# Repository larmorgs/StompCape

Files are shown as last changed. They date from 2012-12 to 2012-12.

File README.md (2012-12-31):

Stomp Cape
=======

Greg Larmore and Matt Moravec

This is the repository for the Stomp Cape--a BeagleBone cape for an open source guitar effects stomp pedal. The pedal will leverage the power of 32-bit embedded linux on the BeagleBone and will be reconfigurable using node.js.

Current Status
=======

Currently the schematic for the cape has been created and is being validated. Software to support the cape is under development.

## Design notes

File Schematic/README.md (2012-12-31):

Stomp Cape
=======

Greg Larmore and Matt Moravec

This is the schematic for the Stomp Cape created in Eagle 6.3.0. It uses the built in Eagle libraries along with the libraries located in the ./lbr folder.

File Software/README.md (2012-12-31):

Stomp Cape
=======

Greg Larmore and Matt Moravec

This is the software that accompanies the cape.

CURRENTLY UNDER DEVELOPMENT.

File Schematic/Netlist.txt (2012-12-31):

Netlist

Exported from BeagleBone-Stomp-v0.1.sch at 12/31/2012 1:25:14 PM

EAGLE Version 6.3.0 Copyright (c) 1988-2012 CadSoft

Net      Part     Pad      Pin        Sheet

1.8V     C18      1        P$1        1
         C4       2        P$2        1
         C5       1        P$1        1
         R1       1        1          1
         U2       3        DVDD       1
         U3       1        OUT        1

3.3V     C1       1        P$1        1
         C11      1        P$1        1
         C14      1        P$1        1
         C19      1        P$1        1
         C2       1        P$1        1
         C6       1        P$1        1
         C7       1        P$1        1
         C8       1        P$1        1
         C9       1        P$1        1
         J1       4        VCC_IN     1
         JP3      1        1          1
         JP3      2        2          1
         JP3      3        3          1
         JP3      4        4          1
         JP3      5        5          1
         JP3      6        6          1
         R10      1        1          1
         R11      1        1          1
         R12      1        1          1
         R13      1        1          1
         R14      1        1          1
         R15      1        1          1
         R16      1        1          1
         R17      2        2          1
         R18      2        2          1
         R19      2        2          1
         R20      2        2          1
         R21      2        2          1
         R22      2        2          1
         R23      2        2          1
         R3       1        1          1
         R4       1        1          1
         R5       1        1          1
         R6       1        1          1
         R7       1        1          1
         R8       1        1          1
         R9       1        1          1
         U$5      49       VDD_3V3EXP 1
         U$5      50       VDD_3V3EXP 1
         U1       29       AVCC       1
         U1       30       DVCC       1
         U2       17       AVDD       1
         U2       2        IOVDD      1
         U2       28       HPVDD      1
         U3       5        EN         1
         U3       8        IN         1
         U4       8        VCC        1
         U5       VDD      VDD        1

5.0V     C15      1        P$1        1
         C16      1        P$1        1
         C17      1        P$1        1
         C3       1        P$1        1
         U$5      53       SYS_5V     1
         U$5      54       SYS_5V     1
         U2       21       SPKVDD_2   1
         U2       24       SPKVDD     1

AGND     C15      2        P$2        1
         C16      2        P$2        1
         C17      2        P$2        1
         C2       2        P$2        1
         C3       2        P$2        1
         C6       2        P$2        1
         C7       2        P$2        1
         C8       2        P$2        1
         FB1      1        P$1        1
         J2       S        S          1
         J3       S        S          1
         U2       16       AVSS       1
         U2       20       SPKVSS_2   1
         U2       25       SPKVSS     1
         U2       29       HPVSS      1
         U2       33       EPAD       1

CODEC_BCLK U$5      77       SPI1_SCLK  1
         U2       7        BCLK       1

CODEC_DIN U$5      71       GPIO3_21   1
         U2       5        DIN        1

CODEC_DOUT U$5      74       SPI1_CS0   1
         U2       4        DOUT       1

CODEC_MCLK U2       8        MCLK       1
         U5       OUT      OUT        1

CODEC_WCLK U$5      75       SPI1_DO    1
         U2       6        WCLK       1

GND      C1       2        P$2        1
         C11      2        P$2        1
         C13      2        P$2        1
         C14      2        P$2        1
         C18      2        P$2        1
         C19      2        P$2        1
         C5       2        P$2        1
         C9       2        P$2        1
         FB1      2        P$2        1
         J1       5        VSS        1
         JP1      1        1          1
         JP1      10       10         1
         JP1      11       11         1
         JP1      12       12         1
         JP1      13       13         1
         JP1      2        2          1
         JP1      3        3          1
         JP1      4        4          1
         JP1      5        5          1
         JP1      6        6          1
         JP1      7        7          1
         JP1      8        8          1
         JP1      9        9          1
         R2       1        1          1
         S1       P$1      P$1        1
         S1       P$2      P$2        1
         U$5      1        GND        1
         U$5      2        GND        1
         U$5      47       GND        1
         U$5      48       GND        1
         U$5      89       GND        1
         U$5      90       GND        1
         U$5      91       GND        1
         U$5      92       GND        1
         U1       27       AVSS       1
         U1       28       DVSS       1
         U1       33       EPAD       1
         U2       1        IOVSS      1
         U2       18       DVSS       1
         U3       4        GND        1
         U3       9        EPAD       1
         U4       4        GND        1
         U5       GND      GND        1

I2C_CLK  R17      1        1          1
         U$5      65       I2C2_SCL   1
         U1       21       P1.6/TA0.1/UCB0SOMI/UCB0SCL/A6/CA6/TDI/TCLK 1
         U2       10       SCL        1
         U4       6        SCL        1

I2C_DATA R18      1        1          1
         U$5      66       I2C2_SDA   1
         U1       22       P1.7/CAOUT/UCB0SIMO/UCB0SDA/A7/CA7/TDO/TDI 1
         U2       9        SDA        1
         U4       5        SDA        1

LED1     JP1      14       14         1
         U1       14       P3.4/TA0.0 1

LED2     JP1      15       15         1
         U1       15       P2.3/TA1.0 1

LED3     JP1      16       16         1
         U1       16       P2.4/TA1.2 1

LED4     JP1      17       17         1
         U1       17       P2.5/TA1.2 1

LED5     JP1      18       18         1
         U1       18       P3.5/TA0.1 1

LED6     JP1      19       19         1
         U1       19       P3.6/TA0.2 1

LED7     JP1      20       20         1
         U1       20       P3.7/TA1CLK/CAOUT 1

N$1      C4       1        P$1        1
         R1       2        2          1
         R2       2        2          1
         U3       3        NR/FB      1

N$3      SPKM     1        P          1
         U2       19       SPKM_2     1
         U2       23       SPKM       1

N$4      SPKP     1        P          1
         U2       22       SPKP_2     1
         U2       26       SPKP       1

N$5      R19      1        1          1
         S1       P$4      P$4        1
         U4       1        A0         1

N$6      C10      2        P$2        1
         J3       T        T          1

N$7      JP2      20       20         1
         R3       2        2          1

N$8      C10      1        P$1        1
         U2       27       HPOUT      1

N$9      C12      1        P$1        1
         J2       T        T          1

N$10     C12      2        P$2        1
         U2       14       MIC1RP     1

N$11     R20      1        1          1
         S1       P$3      P$3        1
         U4       2        A1         1

N$12     R21      1        1          1
         U4       3        A2         1

N$13     JP2      14       14         1
         R9       2        2          1

N$14     JP2      15       15         1
         R8       2        2          1

N$15     JP2      16       16         1
         R7       2        2          1

N$16     JP2      17       17         1
         R6       2        2          1

N$18     R22      1        1          1
         U4       7        WP         1

N$22     JP2      18       18         1
         R5       2        2          1

N$23     JP2      19       19         1
         R4       2        2          1

N$32     J1       6        SBWTCK     1
         U1       24       TEST/SBWTCK 1

N$33     C13      1        P$1        1
         J1       1        SBWTDIO    1
         R23      1        1          1
         U1       23       *RST/NMI/SBWTDIO 1

POT1     JP2      1        1          1
         U1       31       P1.0/TA0CLK/ACLK/A0/CA0 1

POT2     JP2      2        2          1
         U1       1        P1.1/TA0.0/UCA0RXD/UCA0SOMI/A1/CA1 1

POT3     JP2      3        3          1
         U1       2        P1.2/TA0.1/UCA0TXD/UCA0SIMO/A2/CA2 1

POT4     JP2      4        4          1
         U1       3        P1.3/ADC10CLK/CAOUT/VREF-/VEREF-/A3/CA3 1

POT5     JP2      5        5          1
         U1       4        P1.4/SMCLK/UCB0STE/UCA0CLK/VREF+/VEREF+/A4/CA4/TCK 1

POT6     JP2      6        6          1
         U1       5        P1.5/TA0.0/UCB0CLK/UCA0STE/A5/CA5/TMS 1

RESET    U$5      56       SYS_RESETN 1
         U2       31       *RESET     1

STOMP1   JP2      7        7          1
         R16      2        2          1
         U1       6        P3.1/TA1.0 1

STOMP2   JP2      8        8          1
         R15      2        2          1
         U1       7        P3.0/TA0.2 1

STOMP3   JP2      9        9          1
         R14      2        2          1
         U1       9        P2.0/TA1.0 1

STOMP4   JP2      10       10         1
         R13      2        2          1
         U1       10       P2.1/TA1.1 1

STOMP5   JP2      11       11         1
         R12      2        2          1
         U1       11       P2.2/TA1.1 1

STOMP6   JP2      12       12         1
         R11      2        2          1
         U1       12       P3.2/TA1.1 1

STOMP7   JP2      13       13         1
         R10      2        2          1
         U1       13       P3.3/TA1.2 1

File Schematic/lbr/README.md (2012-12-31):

Stomp Cape
=======

Greg Larmore and Matt Moravec

These are the additional libraries used in the Stomp Cape schematic.

The microbuilder.lbr library is courtesy of Adafruit

https://github.com/adafruit/Adafruit-Eagle-Library

The bone.lbr library contains the rest of the necessary parts. The BeagleBone cape outline has been modified from that in Adafruit's microbuilder.lbr. Also the TC2030 symbol has been modified from tag-connect.lbr to reflect the correct pinout for the SPY-BI-TAG adapter.

http://www.tag-connect.com/tag-connect-downloads
http://www.tag-connect.com/SPY-BI-TAG

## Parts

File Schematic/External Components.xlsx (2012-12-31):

Device | Cost (1 piece) | # of pieces | Cost | Website
Rotary Potentiometer - 10k Ohm, Linear | $0.95 | 1 | $0.95 | https://www.sparkfun.com/products/9939
Silver Metal Knob - 14x24mm | $1.50 | 1 | $1.50 | https://www.sparkfun.com/products/10001
LED Holder - 5mm | $0.50 | 1 | $0.50 | https://www.sparkfun.com/products/11147
LED - Basic Green 5mm | $0.35 | 1 | $0.35 | https://www.sparkfun.com/products/9592
Stomp Switch - DPDT | $1.95 | 1 | $1.95 | https://www.sparkfun.com/products/11151
Speaker - PCB Mount | $1.95 | 1 | $1.95 | https://www.sparkfun.com/products/11089
 |  | Total Cost | $7.20

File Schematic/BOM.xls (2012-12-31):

Part | Value | Device | Cost (1 piece) | # of pieces | Cost | Website | Description
C1, C3, C4, C5, C6, C8, C11, C12, C14, C17 | 0.1u | CAP_CERAMIC0402 | $0.10 | 10 | $1.00 | http://www.digikey.com/product-detail/en/C1005X5R0J104K/445-1266-1-ND/567731 | CAP CER 0.1UF 6.3V 10% X5R 0402
C2, C7, C18, C19 | 10u | CAP_CERAMIC0805 | $0.17 | 4 | $0.68 | http://www.digikey.com/product-detail/en/JMK212F106ZG-T/587-1314-1-ND/931091 | CAP CER 10UF 6.3V Y5V 0805
C9 | 0.01u | CAP_CERAMIC0402 | $0.10 | 1 | $0.10 | http://www.digikey.com/product-detail/en/C1005C0G1H100D/445-1235-1-ND/567743 | CAP CER 10PF 50V NP0 0402
C10 | 47u | CAP_CERAMIC0805 | $1.03 | 1 | $1.03 | http://www.digikey.com/product-detail/en/C2012X5R0J476M/445-5987-1-ND/2444028 | CAP CER 47UF 6.3V 20% X5R 0805
C13 | 2.2u | CAP_CERAMIC0402 | $0.27 | 1 | $0.27 | http://www.digikey.com/product-detail/en/C1005X5R0J225M/445-4999-1-ND/2093614 | CAP CER 2.2UF 6.3V 20% X5R 0402
C15, C16 | 22u | CAP_CERAMIC0805 | $0.29 | 2 | $0.58 | http://www.digikey.com/product-detail/en/C2012X5R0J226M%2F1.25/445-1422-1-ND/569088 | CAP CER 22UF 6.3V 20% X5R 0805
FB1 |  | FERRITE_0402 | $0.06 | 1 | $0.06 | http://www.digikey.com/product-detail/en/ACML-0402-102-T/ACML-0402-102-TCT-ND/3060010 | FERRITE CHIP 1000 OHM 100MA 0402
J2, J3 |  | NMJ4HFD2 | $0.85 | 2 | $1.70 | http://www.mouser.com/ProductDetail/REAN-Neutrik/NMJ4HFD2/?qs=sGAEpiMZZMsv2K%252b636k0sW6Lp4d/00Pz | Phone Connectors 2C MONO 2-SPST NC
JP1, JP2 |  | HEADER-1X20ROUND | $0.77 | 2 | $1.54 | http://www.digikey.com/product-detail/en/68000-420HLF/609-3269-ND/1878568 | CONN HEADER 20POS .100 STR TIN
JP3 |  | HEADER-1X6ROUND | $0.32 | 1 | $0.32 | http://www.digikey.com/product-detail/en/68002-406HLF/609-3306-ND/1878494 | CONN HEADER 6POS .100 STR TIN
R1 | 28k | RESISTOR0402 | $0.04 | 1 | $0.04 | http://www.digikey.com/product-detail/en/RMCF0402FT28K0/RMCF0402FT28K0CT-ND/2417612 | RES TF 28K OHM 1% 1/16W 0402
R2 | 56.2k | RESISTOR0402 | $0.04 | 1 | $0.04 | http://www.digikey.com/product-detail/en/RMCF0402FT56K2/RMCF0402FT56K2CT-ND/2417734 | RES TF 56.2K OHM 1% 1/16W 0402
R3, R4, R5, R6, R7, R8, R9 | 100 | RESISTOR0402 | $0.02 | 7 | $0.14 | http://www.digikey.com/product-detail/en/RMCF0402JT100R/RMCF0402JT100RCT-ND/1942933 | RES 100 OHM 1/16W 5% 0402 SMD
R10, R11, R12, R13, R14, R15, R16, R22 | 10k | RESISTOR0402 | $0.02 | 8 | $0.16 | http://www.digikey.com/product-detail/en/RMCF0402JT10K0/RMCF0402JT10K0CT-ND/1942936 | RES 10K OHM 1/16W 5% 0402 SMD
R17, R18, R19, R20, R21 | 4.7k | RESISTOR0402 | $0.02 | 5 | $0.10 | http://www.digikey.com/product-detail/en/RMCF0402JT4K70/RMCF0402JT4K70CT-ND/1942935 | RES 4.7K OHM 1/16W 5% 0402 SMD
R23 | 47k | RESISTOR0402 | $0.10 | 1 | $0.10 | http://www.digikey.com/product-detail/en/ERJ-2GEJ473X/P47KJCT-ND/147021 | RES 47K OHM 1/10W 5% 0402 SMD
SW1 |  | DIPSWITCH_2PIN | $0.60 | 1 | $0.60 | http://www.digikey.com/product-detail/en/219-2MST/CT2192MST-ND/223191 | SWITCH TAPE SEAL 2 POS SMD
U1 |  | MSP430G2553_RHB_32 | $2.87 | 1 | $2.87 | http://www.digikey.com/product-detail/en/MSP430G2553IRHB32T/296-32177-1-ND/3505939 | IC MCU 16BIT 16KB FLASH 32QFN
U2 |  | TLV320AIC3120_RHB_32 | $5.85 | 1 | $5.85 | http://www.mouser.com/ProductDetail/Texas-Instruments/TLV320AIC3120IRHBT/?qs=sGAEpiMZZMsZtvfwwjgKgW9bY1PIvVvY | Audio CODECs Low-Pwr Audio CODEC
U3 |  | TPS73701_DRB_8 | $1.72 | 1 | $1.72 | http://www.digikey.com/product-detail/en/TPS73701DRBR/296-22065-1-ND/1653659 | IC REG LDO ADJ 1A 8-SON
U4 |  | EEPROM_I2C_SOIC8_GENERIC | $0.65 | 1 | $0.65 | http://www.mouser.com/search/ProductDetail.aspx?qs=rZgeL6XvLwaEqwp5Dppodg%3D%3D | EEPROM 256K-Bit I2C Serial CMOS EEPROM
U5 |  | FXO-HC735-12 | $1.31 | 1 | $1.31 | http://www.digikey.com/product-detail/en/FXO-HC735-12/631-1116-1-ND/1244079 | OSCILLATOR 12.000 MHZ 3.3V SMD
 |  |  |  | Total Cost | $20.86

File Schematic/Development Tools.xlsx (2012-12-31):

Device | Cost (1 piece) | # of pieces | Cost | Website | Description
MSP-FET430UIF | $101.00 | 1 | $101.00 | http://www.digikey.com/scripts/DkSearch/dksus.dll?WT.z_header=search_go&lang=en&x=0&y=0&cur=USD | KIT MSP 430/FLASH EMULATION TOOL
SPI-BI-TAG | $29.00 | 1 | $29.00 | http://www.digikey.com/product-search/en?x=0&y=0&lang=en&site=us&KeyWords=spy-bi-tag | ADAPTOR TC2030-MCP MSP430 6PIN
TC2030-MCP | $33.70 | 1 | $33.70 | http://www.mouser.com/ProductDetail/Microchip-Technology/TC2030-MCP/?qs=sGAEpiMZZMtqy0n2JbDgYJnLx9bKOBPX | Programmer Accessories Tag-Connect In-Circt Cable
 |  | Total Cost | $163.70

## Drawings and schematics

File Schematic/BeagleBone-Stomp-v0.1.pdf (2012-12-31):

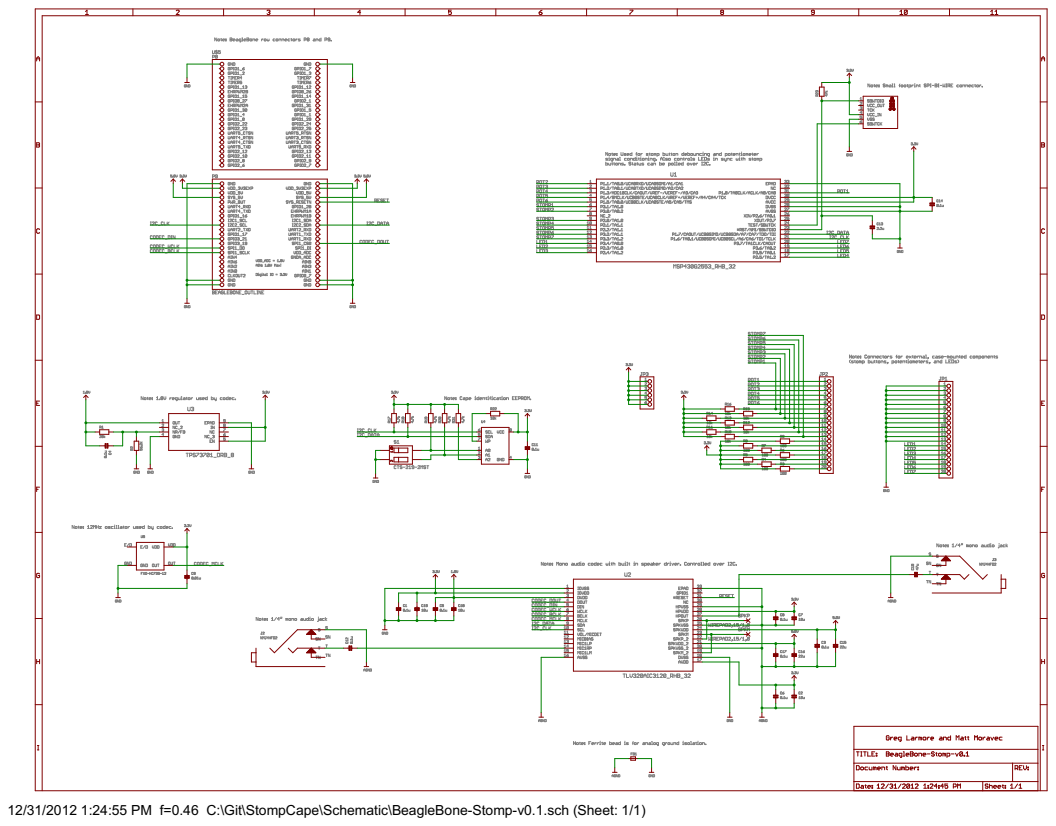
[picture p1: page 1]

12/31/2012 1:24:55 PM f=0.46 C:\Git\StompCape\Schematic\BeagleBone-Stomp-v0.1.sch (Sheet: 1/1)

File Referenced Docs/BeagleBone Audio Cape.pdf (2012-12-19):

# 08/14/2012 BBT

# DATE

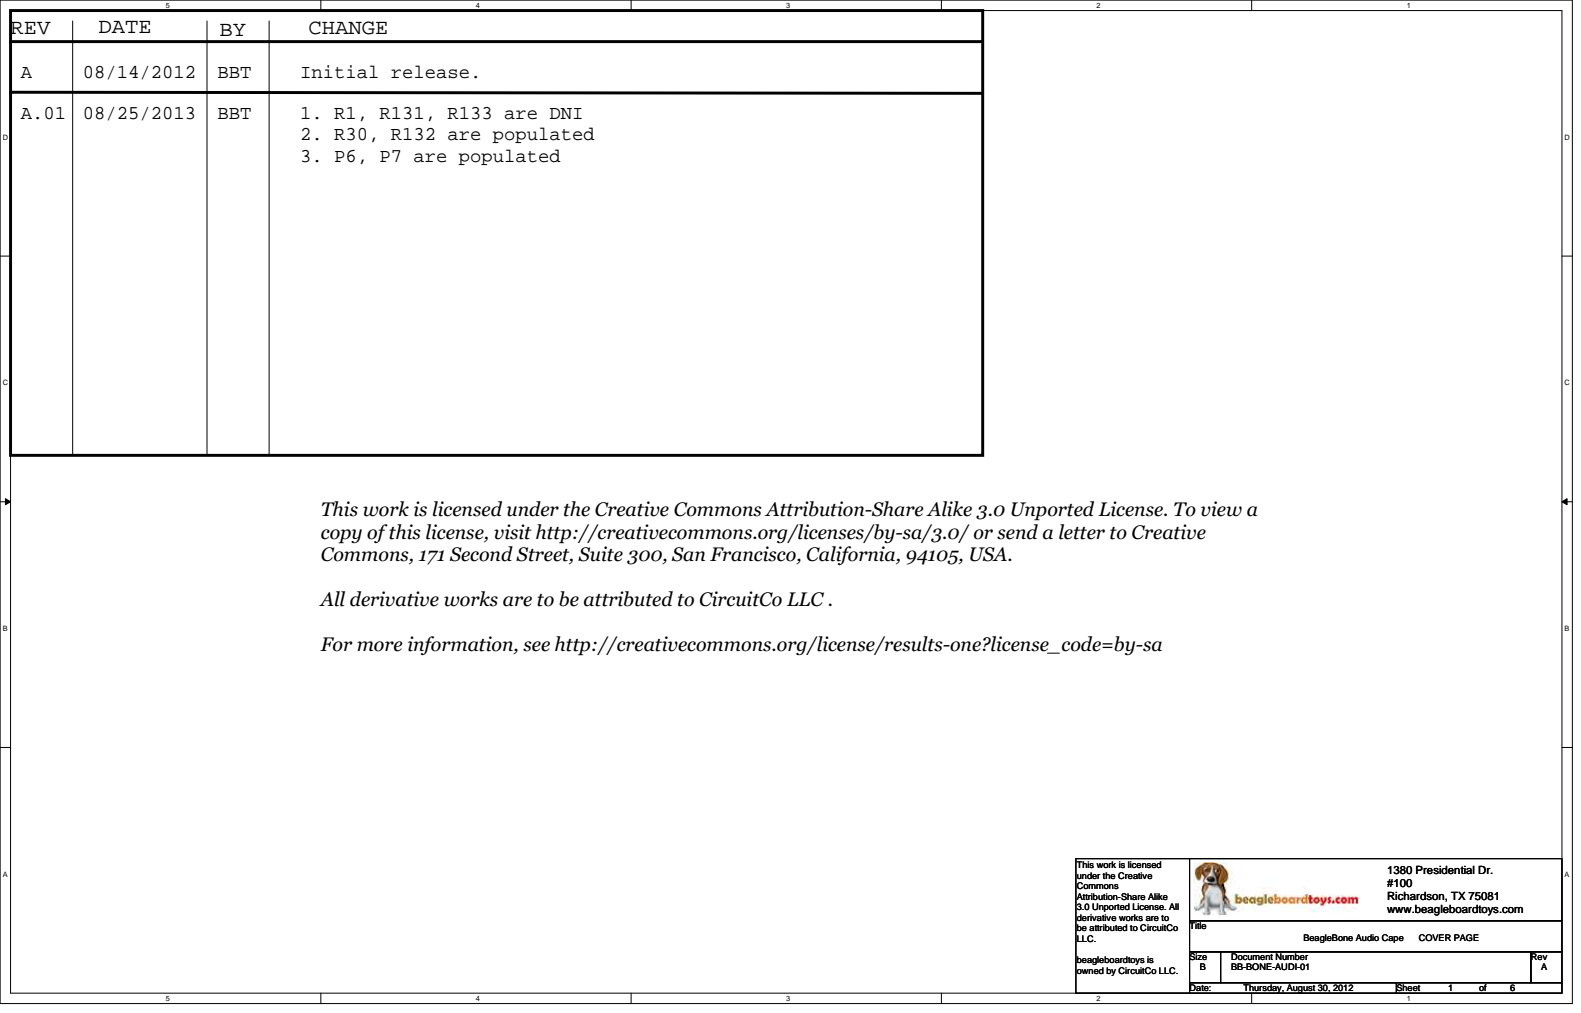
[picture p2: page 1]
REV; CHANGE; Initial release.; BBT; 1. R1, R131, R133 are DNI; 2. R30, R132 are populated 3. P6, P7 are populated; Title; Size; Document Number; Rev; Date:; Sheet; BB-BONE-AUDI-01; BeagleBone Audio Cape; COVER PAGE; Thursday, August 30, 2012

This work is licensed under the Creative Commons Attribution-Share Alike 3.0 Unported License. To view a
copy of this license, visit http://creativecommons.org/licenses/by-sa/3.0/ or send a letter to Creative
Commons, 171 Second Street, Suite 300, San Francisco, California, 94105, USA.

All derivative works are to be attributed to CircuitCo LLC .

For more information, see http://creativecommons.org/license/results-one?license_code=by-sa

This work is licensed
under the Creative
Commons
Attribution-Share Alike
3.0 Unported License. All
derivative works are to
be attributed to CircuitCo
LLC.

1380 Presidential Dr.
Richardson, TX 75081
www.beagleboardtoys.com

beagleboardtoys is
owned by CircuitCo LLC.

# CONN A IN

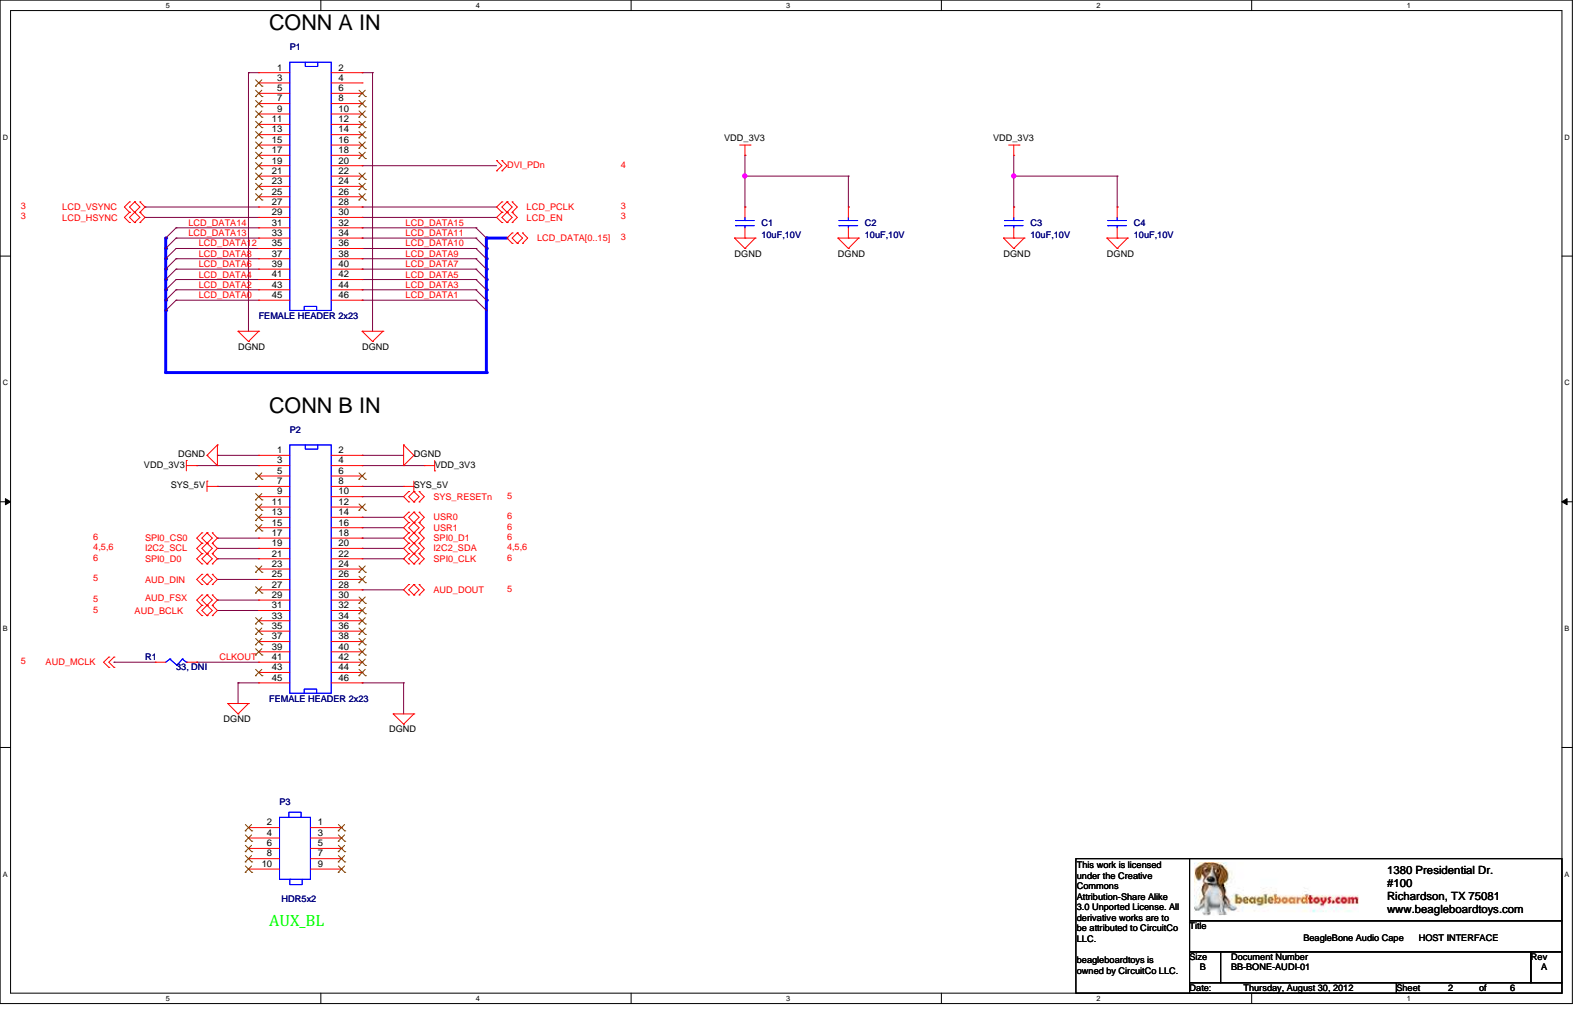
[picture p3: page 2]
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

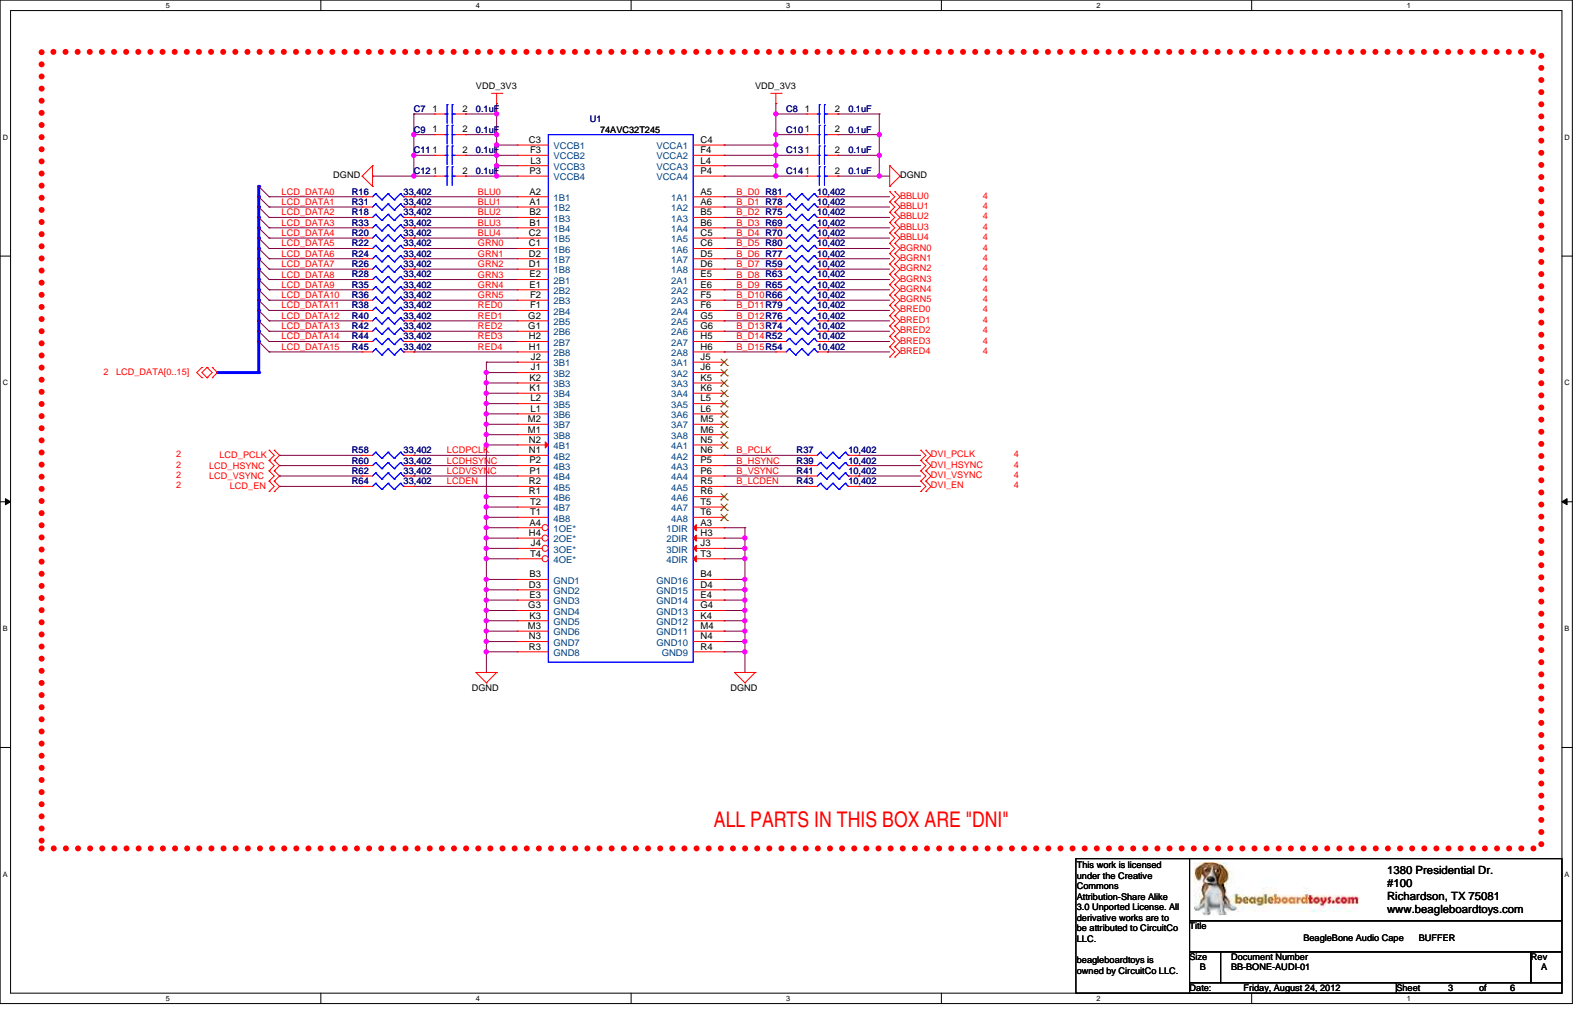
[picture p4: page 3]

ALL PARTS IN THIS BOX ARE "DNI"

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

# ISEL/RESET 13 PD 10 DVDD

t

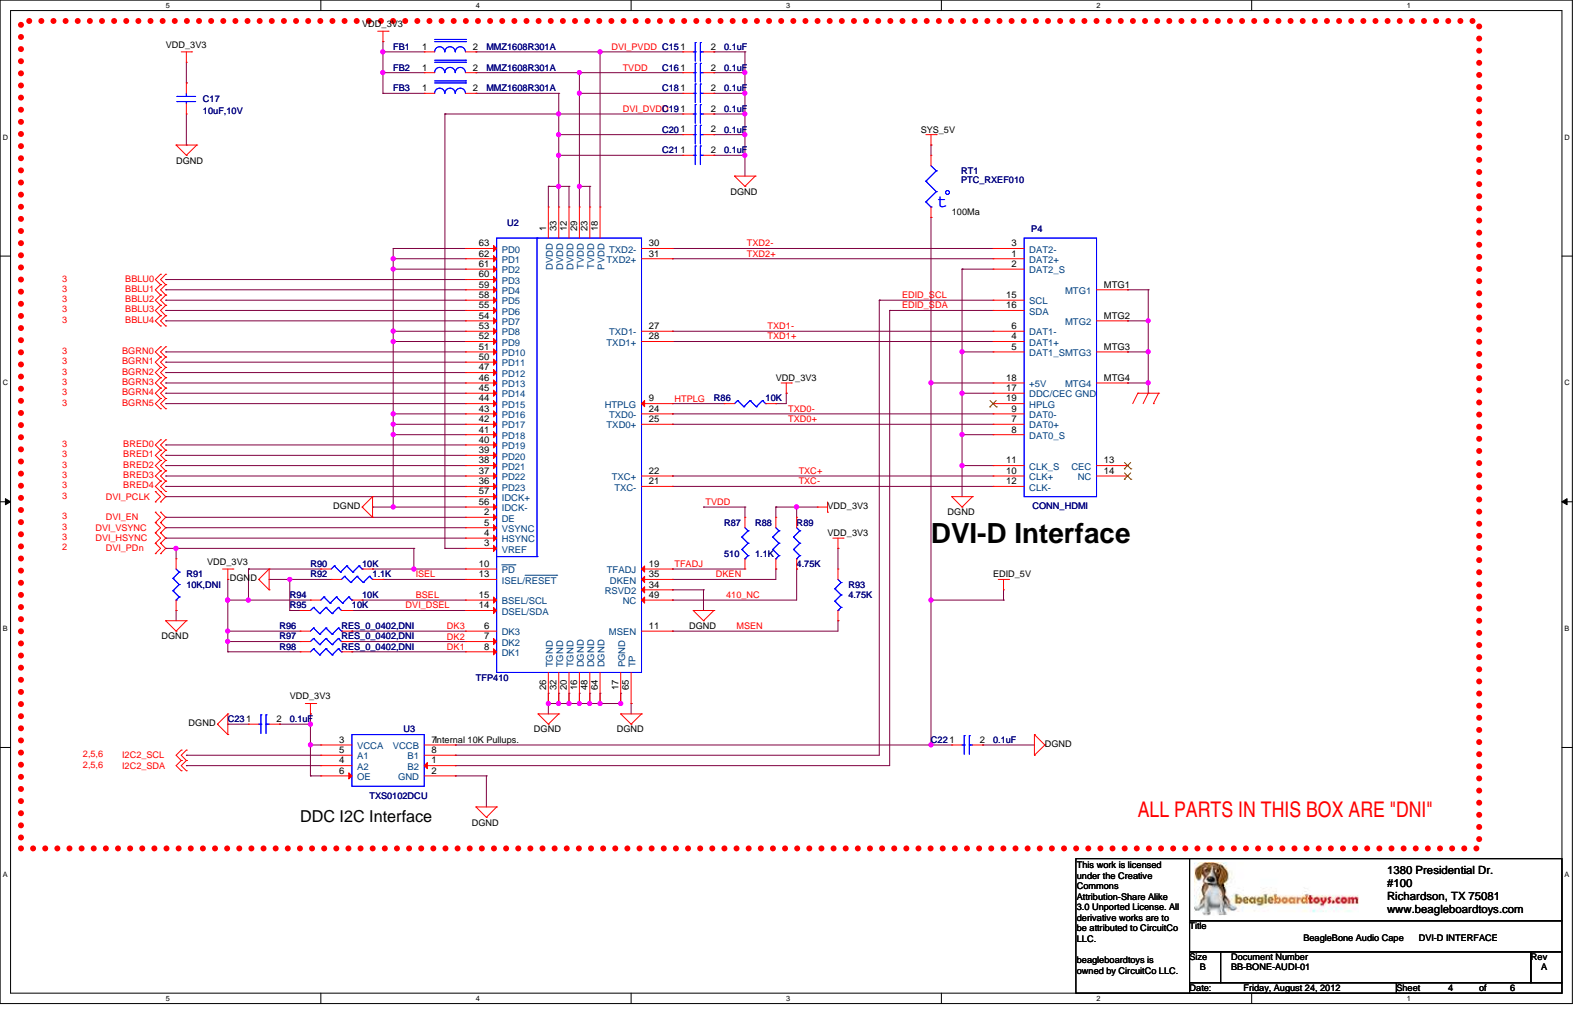
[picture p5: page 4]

DVI_DVDD C19 | 2 0.1uF 1

C20 | 2 0.1uF 1
C21 | 2 0.1uF 1

PVDD 18 TVDD 23 TVDD 29 DGND 48

ALL PARTS IN THIS BOX ARE "DNI"

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

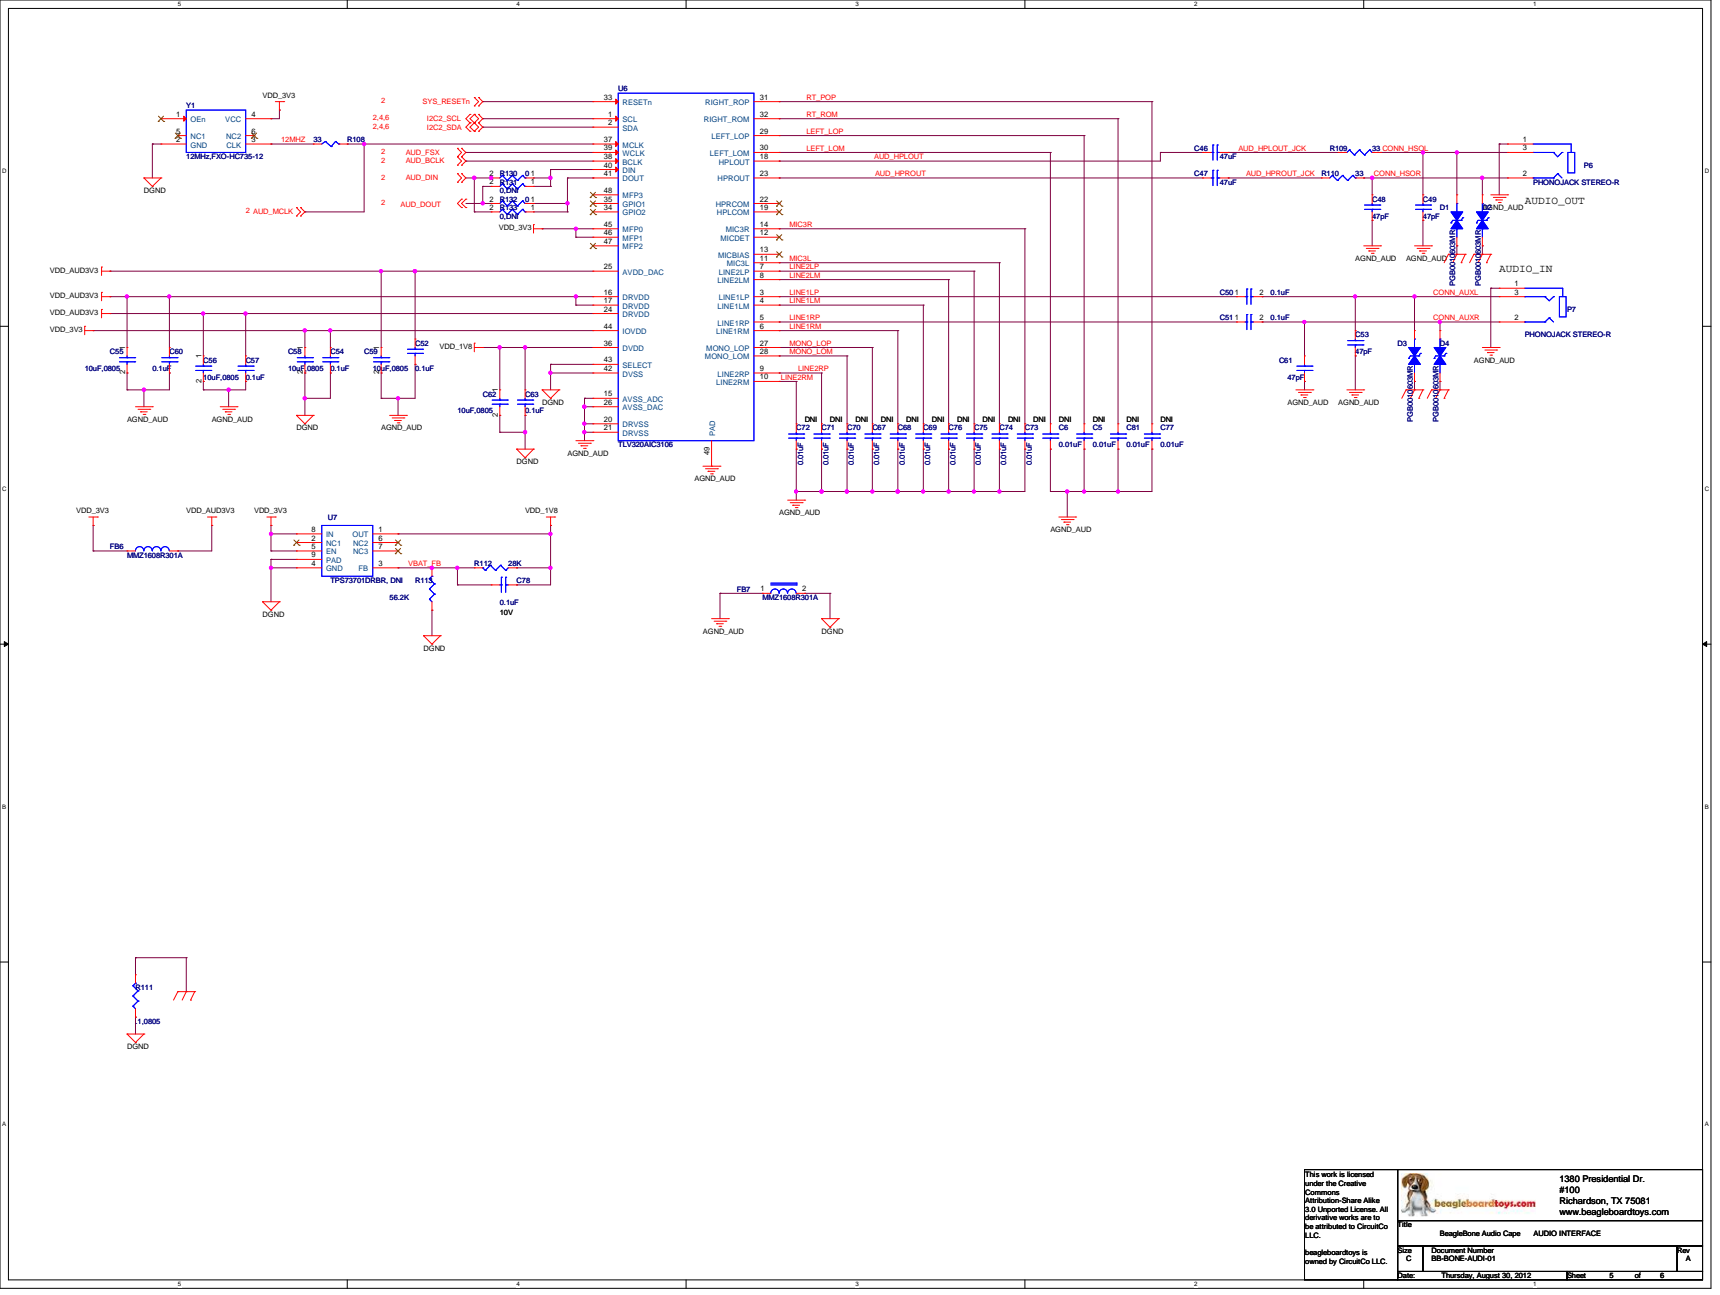
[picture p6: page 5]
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

## LED_COM

## SW1_A0

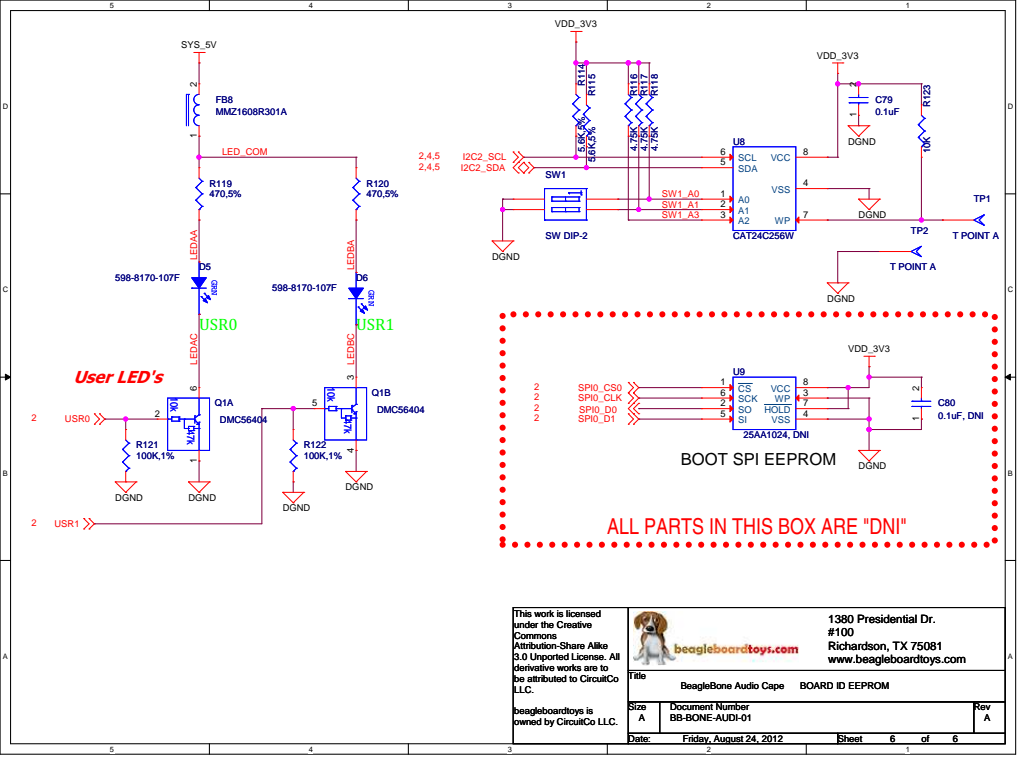
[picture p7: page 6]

ALL PARTS IN THIS BOX ARE "DNI"

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

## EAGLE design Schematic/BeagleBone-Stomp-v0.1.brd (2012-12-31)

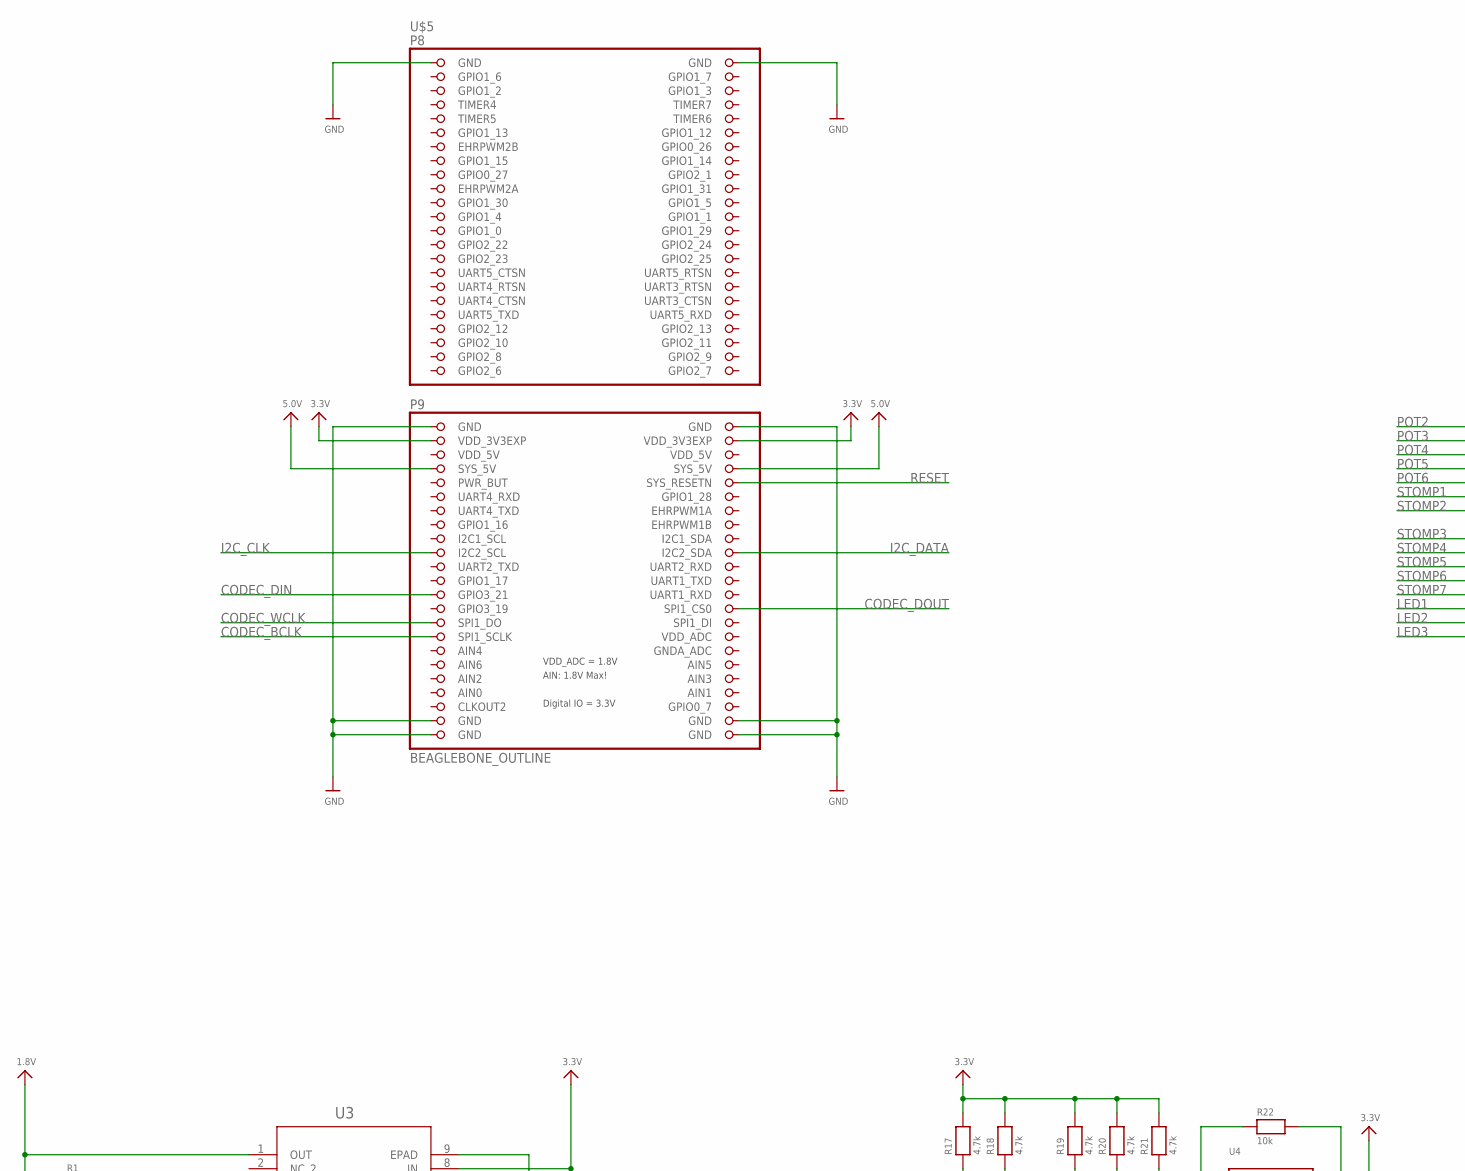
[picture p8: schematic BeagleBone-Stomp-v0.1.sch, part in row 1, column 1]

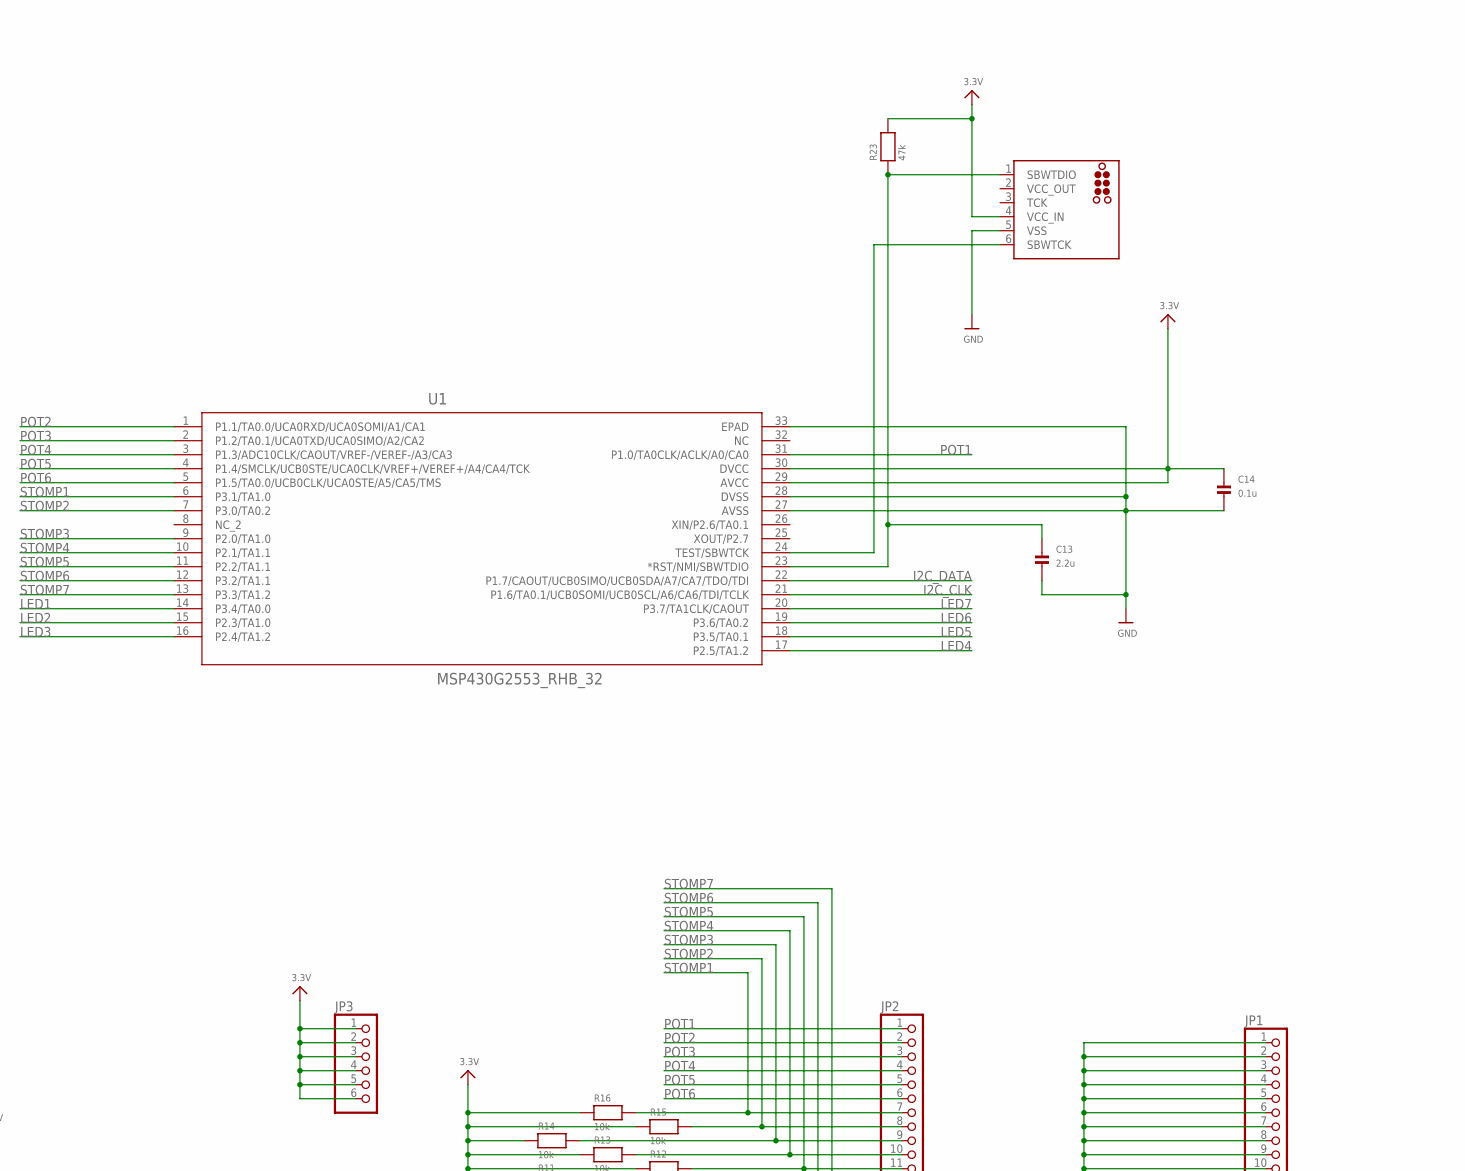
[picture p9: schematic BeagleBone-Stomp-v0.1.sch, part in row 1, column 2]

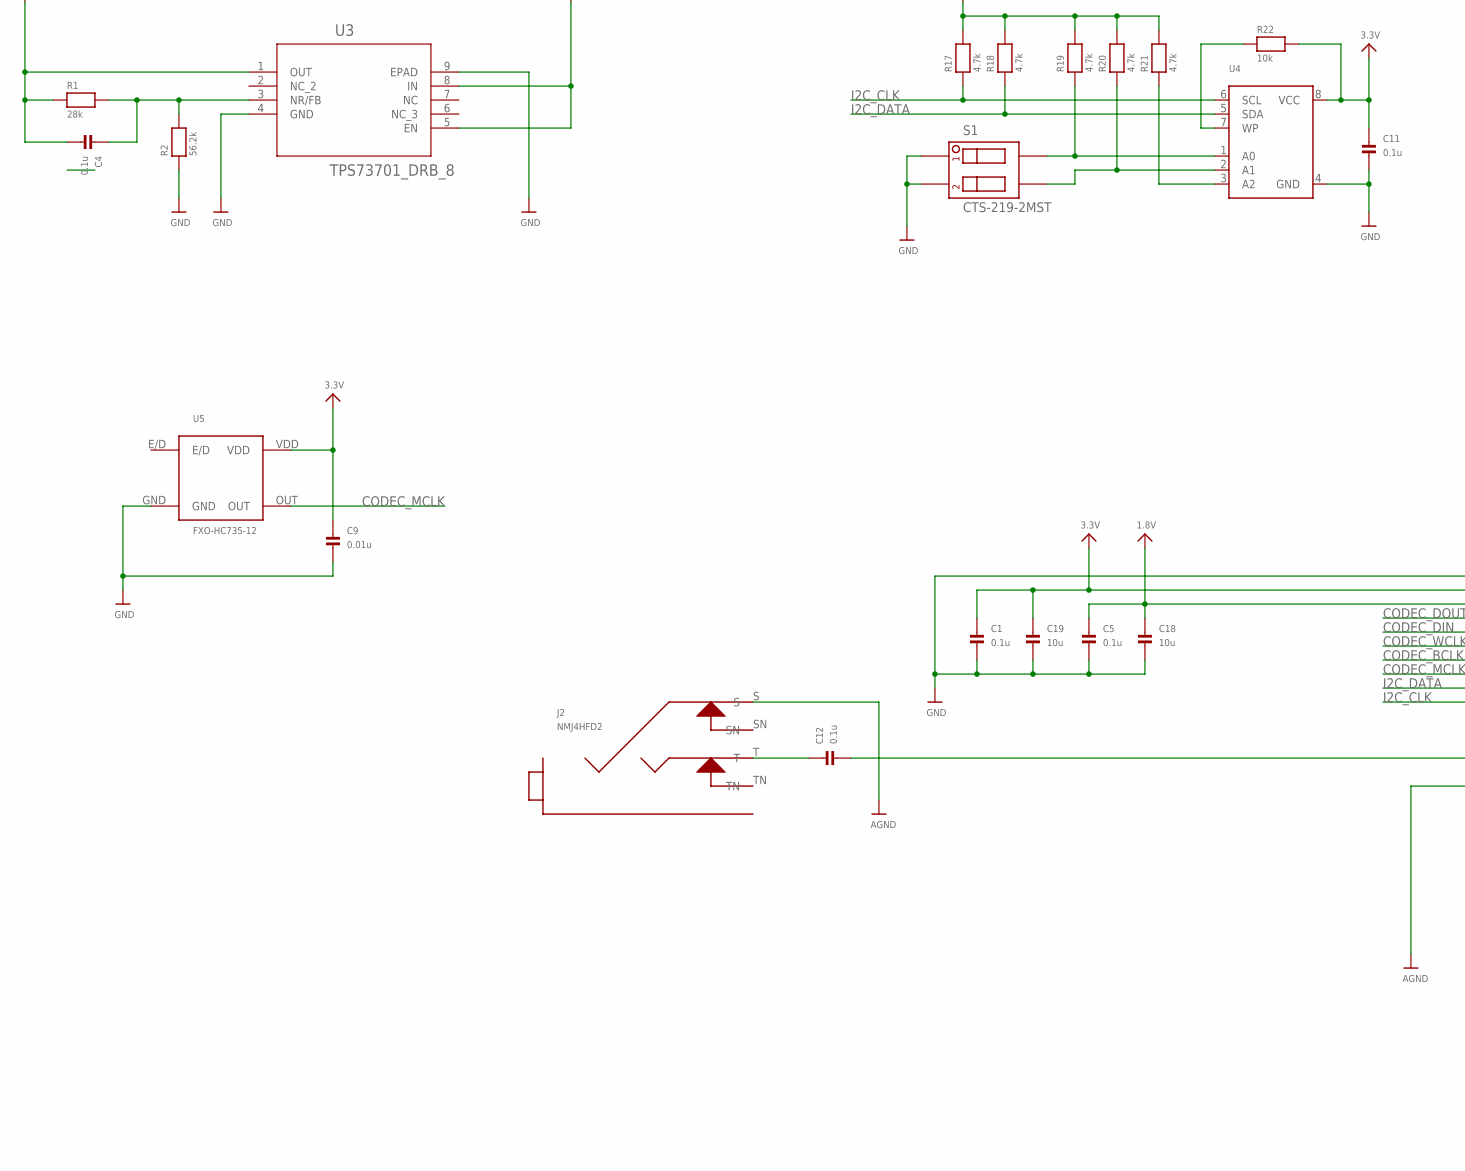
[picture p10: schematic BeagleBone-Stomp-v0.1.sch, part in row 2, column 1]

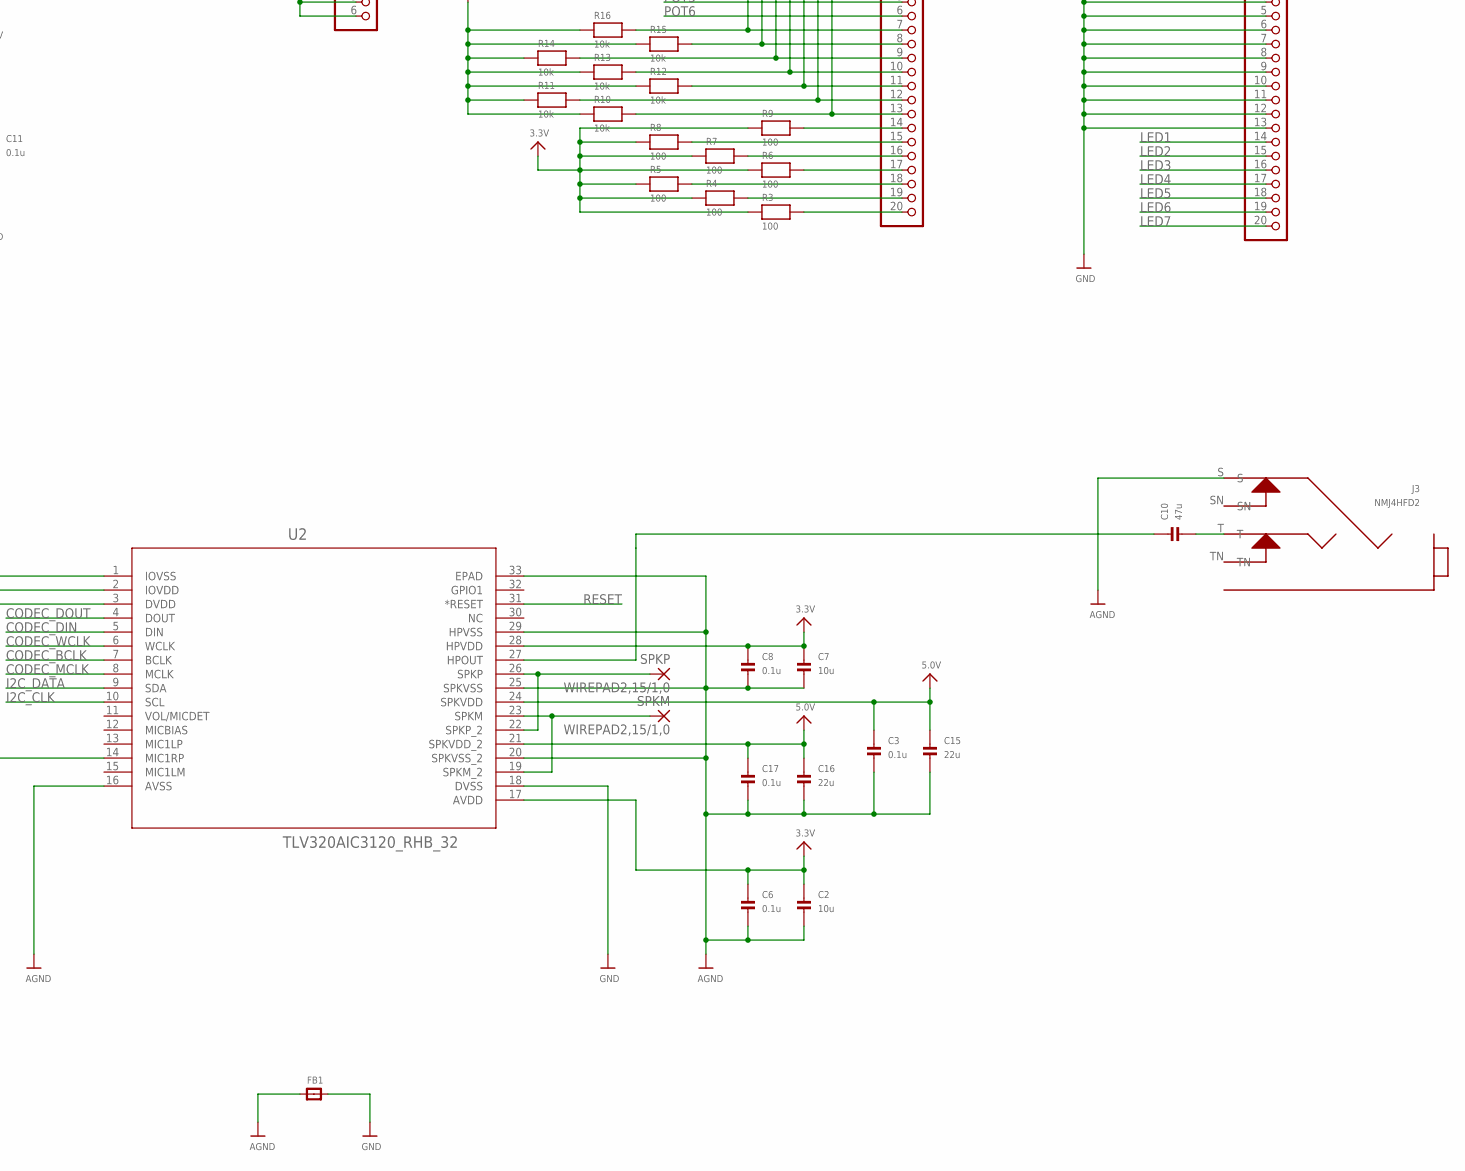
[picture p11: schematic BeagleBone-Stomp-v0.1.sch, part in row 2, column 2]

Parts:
C1, C3, C4, C5, C6, C8, C11, C12, C14, C17: 0.1u; 0402
C2, C7, C18, C19: 10u; 0805
C9: 0.01u; 0402
C10: 47u; 0805
C13: 2.2u; 0402
C15, C16: 22u; 0805
FB1: FERRITE_0402; _0402
J1: TC2030-MCP
J2, J3: NMJ4HFD2
JP1, JP2: HEADER-1X20ROUND; 1X20_ROUND
JP3: HEADER-1X6ROUND; 1X06_ROUND
R1: 28k; 0402
R2: 56.2k; 0402
R3, R4, R5, R6, R7, R8, R9: 100; 0402
R10, R11, R12, R13, R14, R15, R16, R22: 10k; 0402
R17, R18, R19, R20, R21: 4.7k; 0402
R23: 47k; 0402
S1: CTS-219-2MST
SPKM: WIREPAD2,15/1,0; 2,15/1,0
SPKP: WIREPAD2,15/1,0; 2,15/1,0
U1: MSP430G2553_RHB_32; RHB32_3P45X3P45
U2: TLV320AIC3120_RHB_32; RHB32_3P45X3P45
U3: TPS73701_DRB_8; DRB8_1P75X1P5
U4: EEPROM_I2C_SOIC8_GENERIC; SOIC8_150MIL
U5: FXO-HC735-12
U$5: BEAGLEBONE_OUTLINE; BEAGLEBONE_SHIELD

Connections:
1.8V: C4.2, C5.1, C18.1, R1.1, U2.3 (DVDD), U3.1 (OUT)
3.3V: C1.1, C2.1, C6.1, C7.1, C8.1, C9.1, C11.1, C14.1, C19.1, J1.4 (VCC_IN), JP3.1, JP3.2, JP3.3, JP3.4, JP3.5, JP3.6, R3.1, R4.1, R5.1, R6.1, R7.1, R8.1, R9.1, R10.1, R11.1, R12.1, R13.1, R14.1, R15.1, R16.1, R17.2, R18.2, R19.2, R20.2, R21.2, R22.2, R23.2, U1.29 (AVCC), U1.30 (DVCC), U2.2 (IOVDD), U2.17 (AVDD), U2.28 (HPVDD), U3.5 (EN), U3.8 (IN), U4.8 (VCC), U5.VDD, U$5.49 (VDD_3V3EXP), U$5.50 (VDD_3V3EXP)
5.0V: C3.1, C15.1, C16.1, C17.1, U2.21 (SPKVDD_2), U2.24 (SPKVDD), U$5.53 (SYS_5V), U$5.54 (SYS_5V)
AGND: C2.2, C3.2, C6.2, C7.2, C8.2, C15.2, C16.2, C17.2, FB1.1, J2.S, J3.S, U2.16 (AVSS), U2.20 (SPKVSS_2), U2.25 (SPKVSS), U2.29 (HPVSS), U2.33 (EPAD)
CODEC_BCLK: U2.7 (BCLK), U$5.77 (SPI1_SCLK)
CODEC_DIN: U2.5 (DIN), U$5.71 (GPIO3_21)
CODEC_DOUT: U2.4 (DOUT), U$5.74 (SPI1_CS0)
CODEC_MCLK: U2.8 (MCLK), U5.OUT
CODEC_WCLK: U2.6 (WCLK), U$5.75 (SPI1_DO)
GND: C1.2, C5.2, C9.2, C11.2, C13.2, C14.2, C18.2, C19.2, FB1.2, J1.5 (VSS), JP1.1, JP1.2, JP1.3, JP1.4, JP1.5, JP1.6, JP1.7, JP1.8, JP1.9, JP1.10, JP1.11, JP1.12, JP1.13, R2.1, S1.P$1, S1.P$2, U1.27 (AVSS), U1.28 (DVSS), U1.33 (EPAD), U2.1 (IOVSS), U2.18 (DVSS), U3.4 (GND), U3.9 (EPAD), U4.4 (GND), U5.GND, U$5.1 (GND), U$5.2 (GND), U$5.47 (GND), U$5.48 (GND), U$5.89 (GND), U$5.90 (GND), U$5.91 (GND), U$5.92 (GND)
GNDA_ADC: U$5.80 (GNDA_ADC)
I2C_CLK: R17.1, U1.21 (P1.6/TA0.1/UCB0SOMI/UCB0SCL/A6/CA6/TDI/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), U2.10 (SCL), U4.6 (SCL), U$5.65 (I2C2_SCL)
I2C_DATA: R18.1, U1.22 (P1.7/CAOUT/UCB0SIMO/UCB0SDA/A7/CA7/TDO/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), U2.9 (SDA), U4.5 (SDA), U$5.66 (I2C2_SDA)
LED1: JP1.14, U1.14 (P3.4/TA0.0)
LED2: JP1.15, U1.15 (P2.3/TA1.0)
LED3: JP1.16, U1.16 (P2.4/TA1.2)
LED4: JP1.17, U1.17 (P2.5/TA1.2)
LED5: JP1.18, U1.18 (P3.5/TA0.1)
LED6: JP1.19, U1.19 (P3.6/TA0.2)
LED7: JP1.20, U1.20 (P3.7/TA1CLK/CAOUT)
unnamed: C4.1, R1.2, R2.2, U3.3 (NR/FB)
unnamed: SPKM.1, U2.19 (SPKM_2), U2.23 (SPKM)
unnamed: SPKP.1, U2.22 (SPKP_2), U2.26 (SPKP)
unnamed: R19.1, S1.P$4, U4.1 (A0)
unnamed: C10.2, J3.T
unnamed: JP2.20, R3.2
unnamed: C10.1, U2.27 (HPOUT)
unnamed: C12.1, J2.T
unnamed: C12.2, U2.14 (MIC1RP)
unnamed: R20.1, S1.P$3, U4.2 (A1)
unnamed: R21.1, U4.3 (A2)
unnamed: JP2.14, R9.2
unnamed: JP2.15, R8.2
unnamed: JP2.16, R7.2
unnamed: JP2.17, R6.2
unnamed: R22.1, U4.7 (WP)
unnamed: JP2.18, R5.2
unnamed: JP2.19, R4.2
unnamed: J1.6 (SBWTCK), U1.24 (TEST/SBWTCK)
unnamed: C13.1, J1.1 (SBWTDIO), R23.1, U1.23 (*RST/NMI/SBWTDIO)
POT1: JP2.1, U1.31 (P1.0/TA0CLK/ACLK/A0/CA0)
POT2: JP2.2, U1.1 (P1.1/TA0.0/UCA0RXD/UCA0SOMI/A1/CA1)
POT3: JP2.3, U1.2 (P1.2/TA0.1/UCA0TXD/UCA0SIMO/A2/CA2)
POT4: JP2.4, U1.3 (P1.3/ADC10CLK/CAOUT/VREF-/VEREF-/A3/CA3)
POT5: JP2.5, U1.4 (P1.4/SMCLK/UCB0STE/UCA0CLK/VREF+/VEREF+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)
POT6: JP2.6, U1.5 (P1.5/TA0.0/UCB0CLK/UCA0STE/A5/CA5/TMS)
RESET: U2.31 (*RESET), U$5.56 (SYS_RESETN)
STOMP1: JP2.7, R16.2, U1.6 (P3.1/TA1.0)
STOMP2: JP2.8, R15.2, U1.7 (P3.0/TA0.2)
STOMP3: JP2.9, R14.2, U1.9 (P2.0/TA1.0)
STOMP4: JP2.10, R13.2, U1.10 (P2.1/TA1.1)
STOMP5: JP2.11, R12.2, U1.11 (P2.2/TA1.1)
STOMP6: JP2.12, R11.2, U1.12 (P3.2/TA1.1)
STOMP7: JP2.13, R10.2, U1.13 (P3.3/TA1.2)
TCK: J1.3 (TCK)
VCC_OUT: J1.2 (VCC_OUT)
VDD_5V: U$5.51 (VDD_5V), U$5.52 (VDD_5V)
VDD_ADC: U$5.78 (VDD_ADC)

Board: 2 copper layers, 58 parts (0 on the bottom side), 54 nets, no tracks yet.

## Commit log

2012-12-03 Attempting to add files to Git repo
    [BeagleBone-Stomp-v0.1.brd, BeagleBone-Stomp-v0.1.sch]
2012-12-06 connected a few of the pins in the design.
    [BeagleBone-Stomp-v0.1.brd, BeagleBone-Stomp-v0.1.sch]
2012-12-16 Making some changes
    [BeagleBone-Stomp-v0.1.brd, BeagleBone-Stomp-v0.1.sch]
2012-12-19 Adding MSP430 connections
    [BeagleBone-Stomp-v0.1.brd, BeagleBone-Stomp-v0.1.sch]
2012-12-27 Adding crystal and a couple caps. Also added codec connections
    [BeagleBone-Stomp-v0.1.brd, BeagleBone-Stomp-v0.1.sch]
2012-12-28 Adding in EEPROM chip
    [BeagleBone-Stomp-v0.1.brd, BeagleBone-Stomp-v0.1.sch]
2012-12-29 Pretty close to being done just need to check connections on schematic and make BOM
    [BeagleBone-Stomp-v0.1.brd, BeagleBone-Stomp-v0.1.sch]
2012-12-29 Removing arrows and such
    [BeagleBone-Stomp-v0.1.brd, BeagleBone-Stomp-v0.1.sch]
2012-12-31 Cleaning libraries up
    [BeagleBone-Stomp-v0.1.brd, BeagleBone-Stomp-v0.1.sch]
2012-12-31 Adding BOM and netlist
    [BOM.xls]
2012-12-31 Adding in README and another excel sheet for external stuff
    [External Components and Tools.xlsx]
2012-12-31 Adding in external components and dev tools
    [Development Tools.xlsx, External Components and Tools.xlsx, External Components.xlsx]
2012-12-31 Adding PDF of schematic and deleting a random wire that got added
    [BeagleBone-Stomp-v0.1.sch]
2012-12-31 Updating Netlist and Schematic just to be sure
2012-12-31 Adding annotations (and names!) to schematic
    [BeagleBone-Stomp-v0.1.sch]

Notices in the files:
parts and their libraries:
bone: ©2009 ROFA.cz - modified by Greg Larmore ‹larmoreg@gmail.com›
